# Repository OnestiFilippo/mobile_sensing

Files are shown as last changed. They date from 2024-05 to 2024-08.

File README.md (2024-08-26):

# Progetto Laboratorio Industria 4.0

## Mobile Sensing

Realizzazione di un sistema in grado di rilevare buche. 
Il sistema è composto da un dispositivo posizionabile su una bicicletta o un carretto, in grado di rilevare tramite un accelerometro la presenza di buche e la posizione esatta della rilevazione tramite un modulo GPS, e un componente server in grado di ricevere i dati dal dispositivo, di elaborarli e di permetterne la visualizzazione tramite un'interfaccia web.

## Installazione Componente Server

Per il componente server viene utilizzato docker per la creazione dei container necessari per la ricezione dei dati dal dispositivo e per la visualizzazione dei risultati nella pagina web dedicata.
Viene utilizzato un file docker-compose.yml per la creazione dei container. Vengono creati i container per la visualizzazione dei grafici tramite grafana e per la creazione del webserver Apache su cui è possibile accedere alle pagine web. 

```
version: "3.8"
services:
  grafana_mobile_sensing:
    image: grafana/grafana:latest
    container_name: grafana_mobile_sensing
    restart: unless-stopped
    ports:
     - '3003:3000'
  php_mobile_sensing:
    image: php:apache
    container_name: webserver_mobile_sensing
    restart: unless-stopped
    ports:
      - '8083:80'
    volumes:
      - /home/filippoonesti/mobile_sensing/html:/var/www/html/
  mqtt_mobile_sensing:
    image: filippoonesti/mobile_sensing_mqtt:latest
    container_name: mqtt_mobile_sensing
    restart: unless-stopped
    volumes:
      - /home/filippoonesti/mobile_sensing/html/records:/home/filippoonesti/mobile_sensing/html/records
```

Per eseguire il file docker-compose e per avviare i container si utilizza il seguente comando:

```
docker compose up -d
```

Una volta messi in esecuzione tutti i container necessari, è possibile accedere alla pagina web per la visualizzazione dei record all'indirizzo *http://localhost:8083*.

Webpage

## Componente Client

La componente client del progetto consiste in un dispositivo hardware composto da un microcontrollore Raspberry Pi Pico W, un accelerometro, un modulo GPS, un display e due pulsanti.
Sul microcontrollore, tramite MicroPython, quando viene avviata la registrazione, vengono letti i dati dai sensori e, successivamente, vengono inviati alla componente Server tramite MQTT.
I file per l'esecuzione dello script MicroPython e le librerie necessarie sono all'interno della cartella `code_pico`.

MS

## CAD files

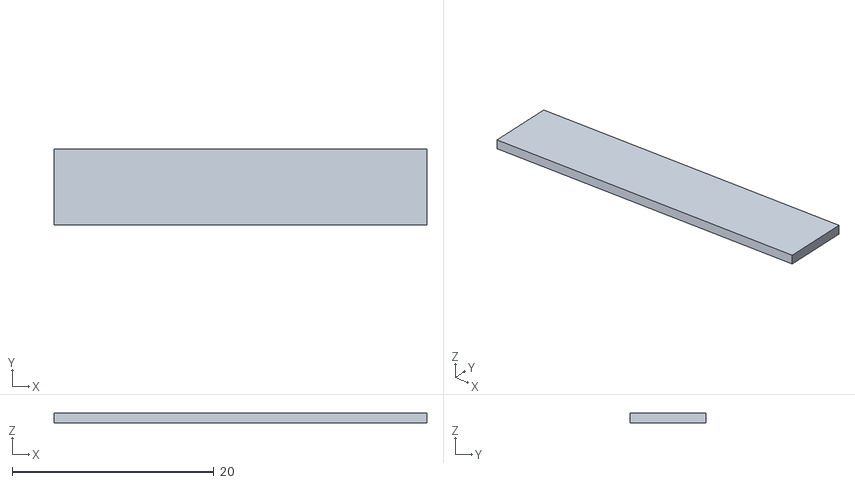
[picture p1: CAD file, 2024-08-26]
STL/Diffuser.stl
37.0 x 7.50 x 1.00

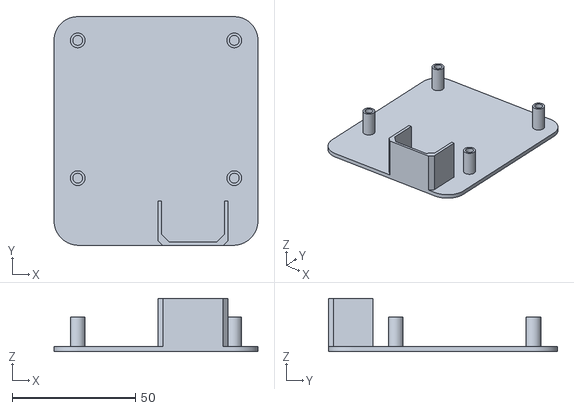
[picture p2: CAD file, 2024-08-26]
STL/Base.stl
82.7 x 92.7 x 21.5

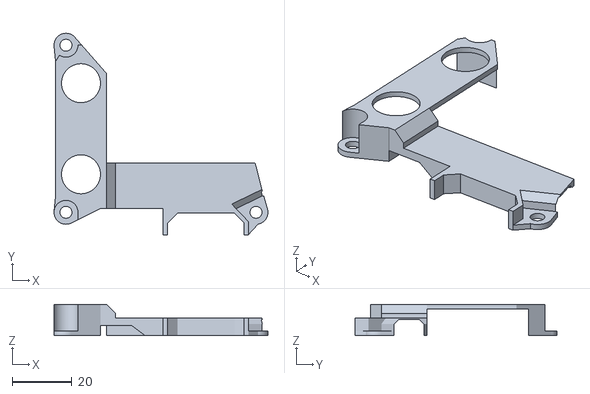
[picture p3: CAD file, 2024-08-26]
STL/ButtonLEDCover.stl
71.5 x 67.3 x 10.5

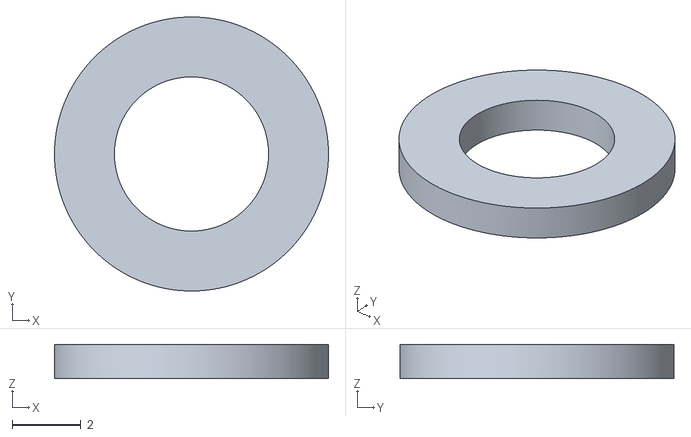
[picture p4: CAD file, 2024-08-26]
STL/Spacer.stl
8.00 x 8.00 x 1

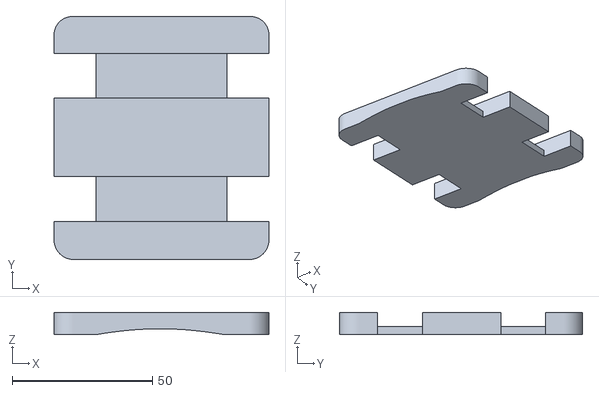
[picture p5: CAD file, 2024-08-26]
STL/BikeSupport.stl
76.7 x 86.7 x 8.00

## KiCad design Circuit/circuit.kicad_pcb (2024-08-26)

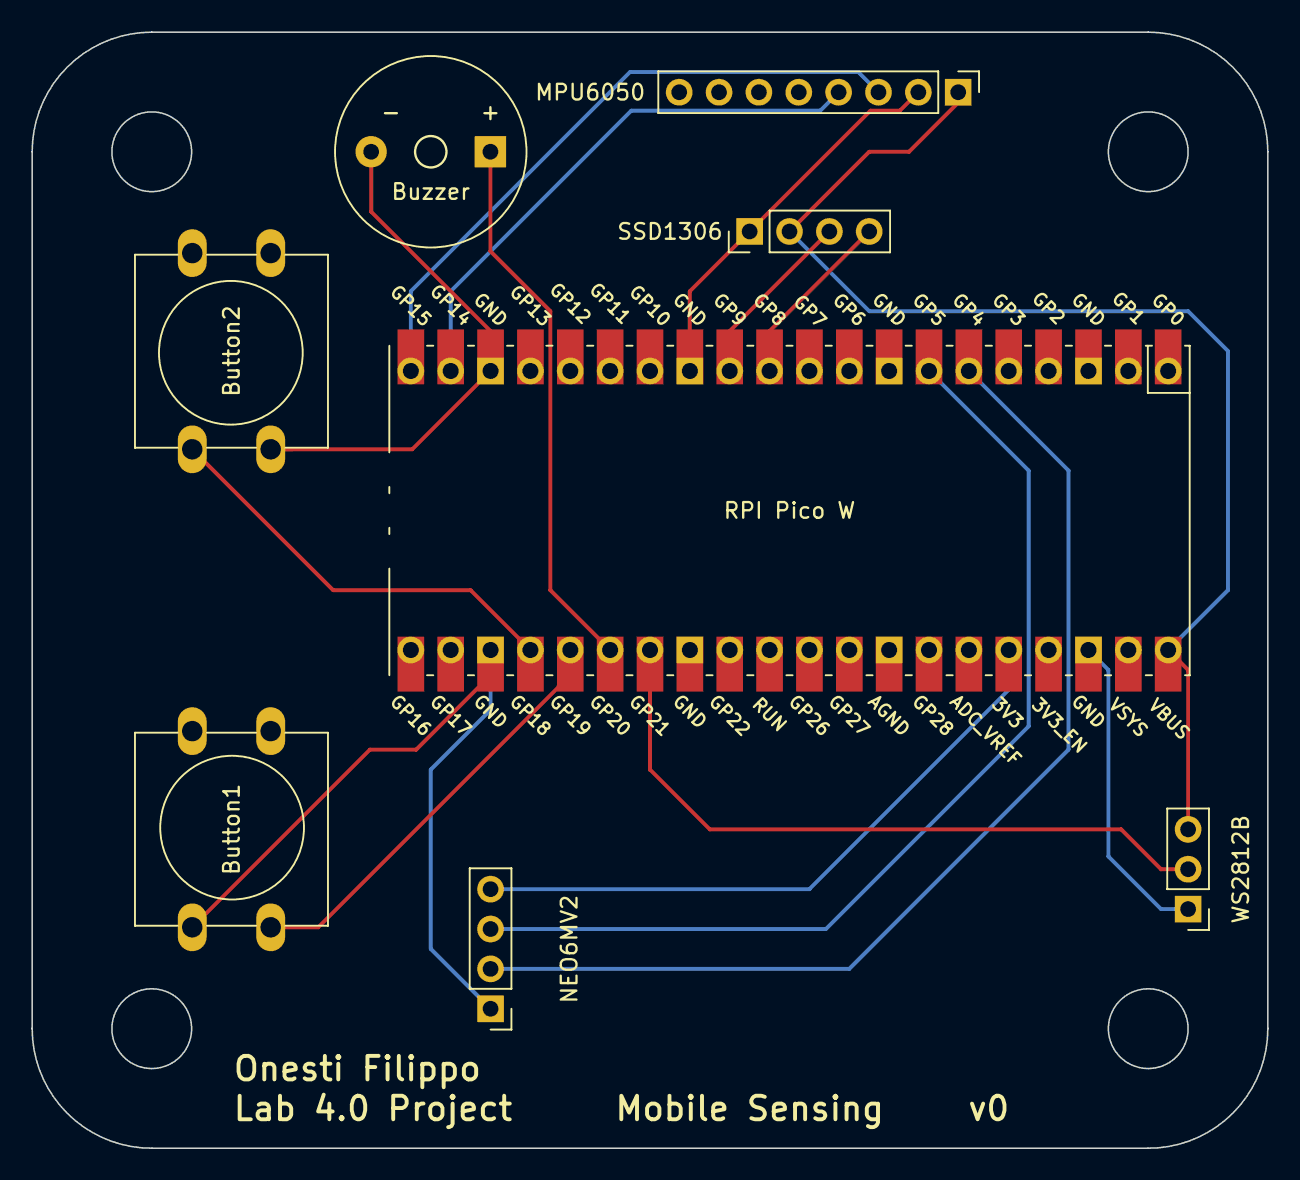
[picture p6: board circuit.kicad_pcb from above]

Board: 2 copper layers, 78.7 x 71.1 mm, 8 parts (0 on the bottom side), 13 nets.

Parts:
J0: SSD1306; PinHeader_1x04_P2.54mm_Vertical
J1: NEO6MV2; PinHeader_1x04_P2.54mm_Vertical
J2: MPU6050; PinHeader_1x08_P2.54mm_Vertical
J3: WS2812B; PinHeader_1x03_P2.54mm_Vertical
J4: Button1; SW_PUSH-12mm
J5: Button2; SW_PUSH-12mm
J6: Buzzer; Buzzer_12x9.5RM7.6
U0: RPI Pico W; RPi_Pico_SMD_TH

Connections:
3.3V: J1.4, U0.36 (3V3)
5V: J0.2, J2.1, J3.3, U0.40 (VBUS)
BUT1: J5.2, U0.24 (GPIO18)
BUT2: J4.2, U0.25 (GPIO19)
BUZZ: J6.1, U0.26 (GPIO20)
GND: J0.1, J1.1, J2.2, J3.1, J4.1, J5.1, J6.2, U0.3 (GND), U0.8 (GND), U0.13 (GND), U0.18 (GND), U0.23 (GND), U0.28 (GND), U0.38 (GND)
LED: J3.2, U0.27 (GPIO21)
RX: J1.3, U0.7 (GPIO5)
SCL_ACC: J2.3, U0.20 (GPIO15)
SCL_DIS: J0.3, U0.12 (GPIO9)
SDA_ACC: J2.4, U0.19 (GPIO14)
SDA_DIS: J0.4, U0.11 (GPIO8)
TX: J1.2, U0.6 (GPIO4)

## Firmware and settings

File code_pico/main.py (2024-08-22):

from machine import Pin, SoftI2C, I2C, PWM, UART
import ssd1306
from time import sleep
from imu import MPU6050
import neopixel
import network
import secrets
from umqttsimple import MQTTClient
import ujson
from micropyGPS import MicropyGPS
import os
import math
import time

# Components initialization
# MPU6050
i2c = I2C(1, sda=Pin(14), scl=Pin(15), freq=400000)
imu = MPU6050(i2c)

# NEOPIXEL
leds = neopixel.NeoPixel(Pin(21), 2)

#BUZZER
buzzer = PWM(Pin(20))

# OLED
i2c = SoftI2C(scl=Pin(9), sda=Pin(8))

oled_width = 128
oled_height = 64

oled = ssd1306.SSD1306_I2C(oled_width, oled_height, i2c)

# NEO6M
gps_module = UART(1, baudrate=9600, tx=Pin(4), rx=Pin(5))

TIMEZONE = 2
my_gps = MicropyGPS(TIMEZONE)

# BUTTONS
button1 = Pin(18, Pin.IN, Pin.PULL_UP)
button2 = Pin(19, Pin.IN, Pin.PULL_UP)

# Variables initialization

previous_time = time.ticks_ms()
angle_y = 0.0

status = 'MAIN'
#z_thresh_value = 20
z_diff_value = 20

records = []
g_values = [0]*10

filename = ""

# MQTT 
mqtt_server = '192.168.1.55'
client_id = "mobile_sensor"
topic_pub = b'records'

# Function to convert GPS data
def convert(parts):
    if (parts[0] == 0):
        return None
        
    data = parts[0]+(parts[1]/60.0)
    # parts[2] contain 'E' or 'W' or 'N' or 'S'
    if (parts[2] == 'S'):
        data = -data
    if (parts[2] == 'W'):
        data = -data

    data = '{0:.6f}'.format(data) # to 6 decimal places
    return str(data)

# Function to send records to the server via MQTT
def send():
    if len(os.listdir("/records")) != 0:
        oled.fill(0)
        oled.text("Connecting to", 5,10)
        oled.text("WiFi..", 5,20)
        oled.show()

        # Connect to WiFi
        wlan = network.WLAN(network.STA_IF)
        wlan.active(True) # power up the WiFi chip
        sleep(5) # wait three seconds for the chip to power up and initialize
        wlan.connect(secrets.SSID, secrets.PASSWORD)
        while not wlan.isconnected():
            sleep(0.2)
        oled.fill(0)
        oled.text("WiFi Connected", 5,10)
        oled.show()
        sleep(2)

        # Connect to MQTT
        client = MQTTClient(client_id, mqtt_server)
        client.connect()
        oled.fill(0)
        oled.text("MQTT Connected", 5,10)
        oled.show()
        sleep(2)

        # Send records 
        for filename in os.listdir("/records"):
            print(filename)
            with open("records/"+filename, "r") as file:
                records_file = file.read()
                file.close()
            
            if records_file:
                if wlan.isconnected():
                    oled.fill(0)
                    oled.text("Sending..", 5,20)
                    oled.text(filename[7:21], 5,40)
                    oled.show()
                    print(records_file)

                    # Publish the record on the topic
                    client.publish(topic_pub, records_file)

                    sleep(2)
                    oled.fill(0)
                    oled.text("Successfully", 5,10)
                    oled.text("sent!", 5,20)
                    oled.show()
                    sleep(2)
                else:
                    oled.fill(0)
                    oled.text("Error while", 5,10)
                    oled.text("connecting", 5,20)
                    oled.show()
                    sleep(3)
                    return 0
        return 1
    else:
        oled.fill(0)
        oled.text("No records", 5,10)
        oled.text("to send!", 5,20)
        oled.show()
        sleep(3)
        return 0

# Function Z_Thresh to detect a Z drop
#def z_thresh(g):
    #print(g[9])
    #if g[9] > z_thresh_value:
    #    return True
    #else:
    #    return False

# Function Z_Diff to detect a Z drop
def z_diff():
    #print(abs(g_values[9]-g_values[8]))
    if abs(g_values[9]-g_values[8]) > z_diff_value:
        # Reset value to avoid multiple detections
        g_values[9] = g_values[8]
        return True
    else:
        return False

# Function to get the angle used to detect a ramp
def get_angle():
    ax = imu.accel.x
    ay = imu.accel.y
    az = imu.accel.z
    gx = imu.gyro.x
    gy = imu.gyro.y
    gz = imu.gyro.z
    
    alpha = 0.98  # Filter coefficient
    
    global previous_time
    global angle_y
    
    current_time = time.ticks_ms()
    dt = time.ticks_diff(current_time, previous_time) / 1000.0
    previous_time = current_time

    # Angle calculation from accelerometer
    accel_angle_y = math.atan2(ax, az) * 180 / math.pi

    # Angle calculation from gyroscope (integration)
    angle_y = alpha * (angle_y + gy * dt) + (1 - alpha) * accel_angle_y

    return abs(int(angle_y))

# Function to draw an arrow on the OLED
def write_arrow(x, y):
    for i in range(0,6):
        oled.pixel(x+i, y-i, 1)
        oled.pixel(x+1+i, y-i, 1)
        oled.pixel(x+3, y-5, 1)
        oled.pixel(x+4, y-5, 1)
        oled.pixel(x+6, y-4, 1)
        oled.pixel(x+5, y-3, 1)
        oled.pixel(x+6, y-3, 1)
        oled.pixel(x+6, y-2, 1)
        oled.show()

# Function to record data
def record(filename):    
    # Z axis acceleration data from the accelerometer
    g=round(imu.accel.z,2)*10
        
    # Update the detections list
    g_values.pop(0)
    g_values.append(abs(g))
    
    # If Z drop detected
    if z_diff():
        try:
            # Get the GPS data and timestamp
            t = my_gps.timestamp
            gpsTime = '{:02d}:{:02d}:{:02}'.format(t[0], t[1], t[2])
            latitude = convert(my_gps.latitude)
            longitude = convert(my_gps.longitude)
            
            # Update the records dictionary
            if latitude != None and longitude != None or latitude == None and longitude == None:
                data_dict = {
                    "datetime": gpsTime,
                    "lat": latitude,
                    "long": longitude,
                    "type":1, # Z Drop
                    "g_value": g_values[9]
                    }
                records.append(data_dict)

                # Write the records to file
                to_write = str(records).replace("'", '"')
                with open(filename, "w") as file:
                    file.write(to_write)
                    file.close()
                print(to_write)
            
            # Feedback to the user
            leds[0] = (0,0,50)
            leds[1] = (0,0,50)
            leds.write()
            buzzer.freq(700)
            buzzer.duty_u16(1000)
            sleep(1)
            leds[0] = (0,0,0)
            leds[1] = (0,0,0)
            leds.write()
            buzzer.duty_u16(0)
        except:
            oled.fill(0)
            oled.text("ERROR!",10,25)
            oled.show()
            sleep(1)
    else:
        leds[0] = (50,0,0)
        leds[1] = (0,0,0)
        leds.write()

    # If a ramp with a slope > 20° is detected save the start and stop coordinates of the ramp
    a = get_angle()
    started = 0
    while a > 20:
        if(started == 0):
            started = 1
            write_arrow(80, 50)
            # Save start coordinates
            try:
                # Get the GPS data and timestamp
                t = my_gps.timestamp
                gpsTime = '{:02d}:{:02d}:{:02}'.format(t[0], t[1], t[2])
                latitude = convert(my_gps.latitude)
                longitude = convert(my_gps.longitude)
                
                # Update the records dictionary
                if latitude != None and longitude != None or latitude == None and longitude == None:
                    data_dict = {
                        "datetime": gpsTime,
                        "lat": latitude,
                        "long": longitude,
                        "type": 2 # Ramp Start
                        }
                    records.append(data_dict)

                    # Write the records to file
                    to_write = str(records).replace("'", '"')
                    with open(filename, "w") as file:
                        file.write(to_write)
                        file.close()
                    print(to_write)

                # Feedback to the user
                leds[1] = (0,50,0)
                leds.write()
            except:
                oled.fill(0)
                oled.text("ERROR!",10,25)
                oled.show()
                time.sleep(1)
            
        a = get_angle()
    else:
        # Save stop coordinates
        if started == 1:
            try:
                # Get the GPS data and timestamp
                t = my_gps.timestamp
                gpsTime = '{:02d}:{:02d}:{:02}'.format(t[0], t[1], t[2])
                latitude = convert(my_gps.latitude)
                longitude = convert(my_gps.longitude)
                
                # Update the records dictionary
                if latitude != None and longitude != None or latitude == None and longitude == None:
                    data_dict = {
                        "datetime": gpsTime,
                        "lat": latitude,
                        "long": longitude,
                        "type": 3 # Ramp Stop
                        }
                    records.append(data_dict)

                    # Write the records to file
                    to_write = str(records).replace("'", '"')
                    with open(filename, "w") as file:
                        file.write(to_write)
                        file.close()
                    print(to_write)

                # Feedback to the user
                leds[1] = (0,0,0)
                leds.write()
            except:
                oled.fill(0)
                oled.text("ERROR!",10,25)
                oled.show()
                time.sleep(1)
            started = 0

# Play a sound when the device is ready
buzzer.freq(700)
buzzer.duty_u16(1000)
leds[0] = (10,10,10)
leds[1] = (10,10,10)
leds.write()
sleep(0.3)
buzzer.freq(800)
buzzer.duty_u16(1000)
leds[0] = (0,0,0)
leds[1] = (0,0,0)
leds.write()
sleep(0.3)
buzzer.freq(900)
buzzer.duty_u16(1000)
leds[0] = (10,10,10)
leds[1] = (10,10,10)
leds.write()
sleep(0.3)
buzzer.duty_u16(0)
leds[0] = (0,0,0)
leds[1] = (0,0,0)
leds.write()

# Main loop
while True:
    # Read the GPS data
    length = gps_module.any()
    if length>0:
        b = gps_module.read(length)
        for x in b:
            msg = my_gps.update(chr(x))

    latitude = convert(my_gps.latitude)
    longitude = convert(my_gps.longitude)

    t = my_gps.timestamp
    # t[0] => hours : t[1] => minutes : t[2] => seconds
    gpsTime = '{:02d}:{:02d}:{:02}'.format(t[0], t[1], t[2])
    
    # STATUS = 'MAIN' => Main menu with two options
    # STATUS = 'RECORD' => Record data and save it to a file
    # STATUS = 'SEND => Send records to the server

    # MAIN MENU
    if status == 'MAIN':
        oled.fill(0)
        oled.text("-> RECORD", 5,20)
        oled.text("-> SEND RECORDS", 5,50)
        if latitude != None and longitude != None or latitude == None and longitude == None:
            oled.text("GPS", 100,5)
        else:
            oled.text("-", 110,5)
        oled.show()

    # RECORDING
    elif status == 'RECORD':
        # Get the timestamp from the GPS
        t = my_gps.timestamp
        dt = my_gps.date_string(formatting="s_dmy")
        ts = '{:02d}-{:02d}'.format(t[0], t[1])
        # Create the filename
        if filename=="":
            filename = "records/record_"+dt+"_"+ts+".json"
        # Call the record function
        record(filename)
        oled.fill(0)

        # Display the data graph on the OLED
        for i in range(1,11):
            oled.text(".", (i*10)+4, 20-int(g_values[i-1]), 1)

        oled.text("> STOP", 5,45)
        if latitude != None and longitude != None or latitude == None and longitude == None:
            oled.text("GPS", 100,45)
        else:
            oled.text("-", 110,45)
        oled.show()

    # SEND RECORDS
    elif status == 'SEND':
        send()
        status = 'MAIN'
    
    # Buttons management
    if button1.value() == 0:
        if status == 'MAIN':
            # Wait for GPS
            #while latitude == None and longitude == None:
            #    oled.fill(0)
            #    oled.text("Waiting GPS..", 5,20)
            #    oled.show()
            #    sleep(0.1)
            
            # Start recording
            records=[]
            status='RECORD'
        sleep(0.2)
            
    if button2.value() == 0:
        # Send records
        if status == 'MAIN':
            status='SEND'
        
        # Stop recording and save the file
        elif status == 'RECORD':
            # Turn leds off
            leds[0] = (0,0,0)
            leds[1] = (0,0,0)
            leds.write()
            # Append the filename to the records
            name = filename[8:]
            data_dict = { "name": name }
            records.append(data_dict)
            to_write = str(records).replace("'", '"')
            with open(filename, "w") as file:
                file.write(to_write)
                file.close()
                
            # Return to the main menu
            status='MAIN'
        sleep(0.2)

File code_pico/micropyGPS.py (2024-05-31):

"""
# MicropyGPS - a GPS NMEA sentence parser for Micropython/Python 3.X
# Copyright (c) 2017 Michael Calvin McCoy (calvin.mccoy@protonmail.com)
# The MIT License (MIT) - see LICENSE file
""" 

# TODO:
# Time Since First Fix
# Distance/Time to Target
# More Helper Functions
# Dynamically limit sentences types to parse

from math import floor, modf

# Import utime or time for fix time handling
try:
    # Assume running on MicroPython
    import utime
except ImportError:
    # Otherwise default to time module for non-embedded implementations
    # Should still support millisecond resolution.
    import time


class MicropyGPS(object):
    """GPS NMEA Sentence Parser. Creates object that stores all relevant GPS data and statistics.
    Parses sentences one character at a time using update(). """

    # Max Number of Characters a valid sentence can be (based on GGA sentence)
    SENTENCE_LIMIT = 90
    __HEMISPHERES = ('N', 'S', 'E', 'W')
    __NO_FIX = 1
    __FIX_2D = 2
    __FIX_3D = 3
    __DIRECTIONS = ('N', 'NNE', 'NE', 'ENE', 'E', 'ESE', 'SE', 'SSE', 'S', 'SSW', 'SW', 'WSW', 'W',
                    'WNW', 'NW', 'NNW')
    __MONTHS = ('January', 'February', 'March', 'April', 'May',
                'June', 'July', 'August', 'September', 'October',
                'November', 'December')

    def __init__(self, local_offset=0, location_formatting='ddm'):
        """
        Setup GPS Object Status Flags, Internal Data Registers, etc
            local_offset (int): Timzone Difference to UTC
            location_formatting (str): Style For Presenting Longitude/Latitude:
                                       Decimal Degree Minute (ddm) - 40° 26.767′ N
                                       Degrees Minutes Seconds (dms) - 40° 26′ 46″ N
                                       Decimal Degrees (dd) - 40.446° N
        """

        #####################
        # Object Status Flags
        self.sentence_active = False
        self.active_segment = 0
        self.process_crc = False
        self.gps_segments = []
        self.crc_xor = 0
        self.char_count = 0
        self.fix_time = 0

        #####################
        # Sentence Statistics
        self.crc_fails = 0
        self.clean_sentences = 0
        self.parsed_sentences = 0

        #####################
        # Logging Related
        self.log_handle = None
        self.log_en = False

        #####################
        # Data From Sentences
        # Time
        self.timestamp = [0, 0, 0.0]
        self.date = [0, 0, 0]
        self.local_offset = local_offset

        # Position/Motion
        self._latitude = [0, 0.0, 'N']
        self._longitude = [0, 0.0, 'W']
        self.coord_format = location_formatting
        self.speed = [0.0, 0.0, 0.0]
        self.course = 0.0
        self.altitude = 0.0
        self.geoid_height = 0.0

        # GPS Info
        self.satellites_in_view = 0
        self.satellites_in_use = 0
        self.satellites_used = []
        self.last_sv_sentence = 0
        self.total_sv_sentences = 0
        self.satellite_data = dict()
        self.hdop = 0.0
        self.pdop = 0.0
        self.vdop = 0.0
        self.valid = False
        self.fix_stat = 0
        self.fix_type = 1

    ########################################
    # Coordinates Translation Functions
    ########################################
    @property
    def latitude(self):
        """Format Latitude Data Correctly"""
        if self.coord_format == 'dd':
            decimal_degrees = self._latitude[0] + (self._latitude[1] / 60)
            return [decimal_degrees, self._latitude[2]]
        elif self.coord_format == 'dms':
            minute_parts = modf(self._latitude[1])
            seconds = round(minute_parts[0] * 60)
            return [self._latitude[0], int(minute_parts[1]), seconds, self._latitude[2]]
        else:
            return self._latitude

    @property
    def longitude(self):
        """Format Longitude Data Correctly"""
        if self.coord_format == 'dd':
            decimal_degrees = self._longitude[0] + (self._longitude[1] / 60)
            return [decimal_degrees, self._longitude[2]]
        elif self.coord_format == 'dms':
            minute_parts = modf(self._longitude[1])
            seconds = round(minute_parts[0] * 60)
            return [self._longitude[0], int(minute_parts[1]), seconds, self._longitude[2]]
        else:
            return self._longitude

    ########################################
    # Logging Related Functions
    ########################################
    def start_logging(self, target_file, mode="append"):
        """
        Create GPS data log object
        """
        # Set Write Mode Overwrite or Append
        mode_code = 'w' if mode == 'new' else 'a'

        try:
            self.log_handle = open(target_file, mode_code)
        except AttributeError:
            print("Invalid FileName")
            return False

        self.log_en = True
        return True

    def stop_logging(self):
        """
        Closes the log file handler and disables further logging
        """
        try:
            self.log_handle.close()
        except AttributeError:
            print("Invalid Handle")
            return False

        self.log_en = False
        return True

    def write_log(self, log_string):
        """Attempts to write the last valid NMEA sentence character to the active file handler
        """
        try:
            self.log_handle.write(log_string)
        except TypeError:
            return False
        return True

    ########################################
    # Sentence Parsers
    ########################################
    def gprmc(self):
        """Parse Recommended Minimum Specific GPS/Transit data (RMC)Sentence.
        Updates UTC timestamp, latitude, longitude, Course, Speed, Date, and fix status
        """

        # UTC Timestamp
        try:
            utc_string = self.gps_segments[1]

            if utc_string:  # Possible timestamp found
                hours = (int(utc_string[0:2]) + self.local_offset) % 24
                minutes = int(utc_string[2:4])
                seconds = float(utc_string[4:])
                self.timestamp = [hours, minutes, seconds]
            else:  # No Time stamp yet
                self.timestamp = [0, 0, 0.0]

        except ValueError:  # Bad Timestamp value present
            return False

        # Date stamp
        try:
            date_string = self.gps_segments[9]

            # Date string printer function assumes to be year >=2000,
            # date_string() must be supplied with the correct century argument to display correctly
            if date_string:  # Possible date stamp found
                day = int(date_string[0:2])
                month = int(date_string[2:4])
                year = int(date_string[4:6])
                self.date = (day, month, year)
            else:  # No Date stamp yet
                self.date = (0, 0, 0)
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

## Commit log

2024-05-24 Added buttons style webpage
2024-05-31 Added Micropython Pico Files
2024-08-22 Updated Pico files
